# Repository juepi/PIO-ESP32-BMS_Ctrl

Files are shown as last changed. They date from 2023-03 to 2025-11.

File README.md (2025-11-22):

# Introduction 
This project is intended to be used as an WiFi/MQTT interface to the [Daly Smart BMS Systems](https://www.aliexpress.com/store/4165007) and Victron VE.Direct devices based on my PlatformIO ESP32 Template.  
Primarily, the code reads status data from the Daly BMS, Victron VE.Direct PV charger and SmartShunt and sends it to your MQTT broker at a configurable interval. It automatically switches the load-SSR on if the batteries are fully charged (2 configurable SOC limits) and off if the batteries are drained (also configureable SOC limit). Load-SSR can also be switched manually by setting the corresponding MQTT topic to `on` or `off`. The primary source for the battery SOC is the **Victron SmartShunt**.  
Last but not least, the firmware also allows you to handle an external active balancer through an additional SSR as recommended by [Andy](https://www.youtube.com/watch?v=yPmwrPOwC3g). However, i have added a second condition beside the 3.4V cell voltage: we're only enabling the active balancer if the voltage difference between the highest and lowest cell is above an configurable threshold (defaults to 30mV, configurable via MQTT topic `t_Ctrl_Cfg_SSR2_CdiffOn`).  
To configure the firmware for your needs, see files `user-config.h` and `mqtt-ota-config.h`, also see [**PlatformIO ESP32 Template**](https://github.com/juepi/PIO-ESP32-Template) readme (WiFi setup etc.).

## Mandatory Hardware Requirements
- 1x [WEMOS S2 Mini](https://www.wemos.cc/en/latest/s2/s2_mini.html) or any other ESP32 should work (adopt `platformio.ini`to your needs)
- 1x [Daly Smart BMS Systems](https://www.aliexpress.com/store/4165007) with UART port
- a Lithium battery fitting your requirements and BMS
- 1x [Victron SmartSolar](https://www.victronenergy.com/solar-charge-controllers/smartsolar-100-30-100-50) charger (or any other charger supporting the text version of the VE.Direct protocol)
- 1x [Victron SmartShunt](https://www.victronenergy.com/battery-monitors/smart-battery-shunt) with the amps required for your setup
- 3x [ADUM1201 UART Isolators](https://www.amazon.de/s?k=adum1201) or any other digital isolators you prefer
- 1x [AQW212EH Optocoupler](https://na.industrial.panasonic.com/products/relays-contactors/semiconductor-relays/lineup/photomos-relays/series/12512/model/12513)
- 1x [Active Balancer](https://aliexpress.com/item/4001176521939.html)
- a local WiFi network with a MQTT broker
- Sunlight. :wink:

## Status
What you are looking at here is the **second major release** of this firmware. If you want to see how it all started or you're interested in the problems I've encountered up to this point, take a look at the [final v1 release readme](https://github.com/juepi/PIO-ESP32-BMS_Ctrl/tree/v1.3.0).  
The hardware part is also finished now, see [KiCad folder](https://github.com/juepi/PIO-ESP32-BMS_Ctrl/tree/main/KiCad).

## Safety Guide
Keep in mind that you are working with potentially dangerous electricity levels depending on the hardware you use. Take any precautions necessary!

## Local Requirements
You need to do the initial battery setup on the Daly BMS using the included Bluetooth adapter and Daly's SmartBMS app, as the used [library](https://github.com/maland16/daly-bms-uart) does not support setting configuration parameters. Victron devices can use the VictronConnect App in parallel to the (read only) serial output on the VE.Direct port.  
An active balancer is highly recommended, as the internal passive balancer of the Daly BMS is useless. [Andy from the Off-Grid Garage](https://www.youtube.com/watch?v=yPmwrPOwC3g) has picked up this topic recently, and i've decided to add the active-balancing control as he suggests it into the firmware. Note that you will need an active balancer that will allow you to start the balancing by shorting 2 pins, like [this one from AliExpress](https://aliexpress.com/item/4001176521939.html). You will need to remove the solder chunk from the pads labeled "Run", this will reveal 2 seperate soldering pads. Solder 2 wires to the pads and connect them to an optocoupler output, in example [AQW212EH](https://na.industrial.panasonic.com/products/relays-contactors/semiconductor-relays/lineup/photomos-relays/series/12512/model/12513).

## An important notice on connecting the ESP32 to your BMS and VE.Direct
Take caution when connecting the ESP to the UART ports: the internal electronics of the BMS (including UART port) use "battery ground", whereas other connected devices (i.e. load, charger) use the "power ground". **NEVER EVER** connect these different grounds or magic smoke will leave your electronics! To avoid this, make sure to isolate **anything** coming from or going into the UART ports of the Daly BMS and your VE.Direct devices. For UART RX/TX, a **ADUM1201** isolator chip works well for me.

## Credits
Thanks to [maland16 and softwarecrash](https://github.com/maland16/daly-bms-uart) for providing a library to interact with the Daly Smart BMS.  
Thanks to [cterwilliger](https://github.com/cterwilliger/VeDirectFrameHandler/tree/master) for his Victron VE.Direct frame handler, which has been integrated into this project since v1.2.0. Note that the source is in the lib directory, not from github, as i needed to include [the buffer overflow patch](https://github.com/cterwilliger/VeDirectFrameHandler/pull/10). I have also added a frameCounter which increments when a valid frame is decoded (to ease handling of fresh data) and a function which looks up array index numbers by Name label (required for SmartShunt!).

# Bugs and Workarounds
- Both data frame arrays of the VeDirectFrameHandler (Charger and SmartShunt) keep increasing over time due to transmission/decoding errors (I assume!) leading to new (non-existing) data labels/values that are added to the arrays. VeDirectFrameHandler maxes out at 40 Labels, so this should not lead to any problems (in terms of buffer overflow), not sure how this is possible however as every frame has a checksum. Due to this problem, also garbage values will be decoded every now and then, so I've added additional validity checks when new data was received (especially SoC).
- VeDirectFrameHandler data from the SmartShunt is "sorted" randomly in the veValue/veName arrays, which breaks the "hardcoded" index numbers I used to get the values from the data arrays. I've fixed this by adding a function to the library that allows you to fetch the arrays index number from a given veName tag. This may also happen with data from the SmartSolar chargers (one out of 2 chargers show this "problem" in my setup).
- OneWire doesn't seem to work on high-numbered GPIO pins (tested with > 36); using IO4 works fine!
- It seems that a high frequency toggling of SSR1 and SSR3 relay may occured at firmware boot - i have not been able to identify the root cause, it only happens when the SSRs automatic-mode is enabled. Done some obviously not so successful improvements over time, but as of **v2.6.1** this error still seems to occur randomly. My latest idea on how to work around this issue was to delay handling of the "auto" SSR settings for 15sec after firmware boot with **v2.7.0**. Time will tell if this helped, first tests look promising.
- An **"offgrid mode"** has been added (**v2.4.3**) as i've experienced that certain battery loads (like my offgrid inverter) causes the OneWire communication to fail. I assume that the inverter causes high noise on the DC wires, but as only OneWire communication is affected, i decided to add this MQTT on/off switchable function to allow skipping OneWire readouts (all sensors will be set to 11°C in offgrid mode, see `t_Ctrl_Cfg_Offgrid_Mode` in `user-config.h`). Plugging in the offgrid inverter is only done in case of a long lasting power outage, which has not happened yet (and hopefully never will), so i can live with that limitation. **A note on failing OneWire communication:** in my case the only way to recover OW-communication was to power down the ESP (remove power from the OW sensors), it seems that the controller inside the sensors hung and rebooting the ESP did not help.
- Although all serial communication to the BMS and Victron devices uses some sort of CRC, it rarely happens that implausible values are reported. To avoid reacting with failsafe actions due to wrong values, several plausibility checks have been added starting with `v2.0.2`.

# Version History

## v2.0.0
- Initial Commit, removed overhead from v1
- Improved handling of SSRs (manual switching through MQTT)

## v2.0.1
- Added condition to enable balancer on large cell voltage diff
- Removed condition to enable balancer on PV power threshold
- removed balancer "minimum ON duration" timer
- cleaned up serial connection state handling
- added more textual output to `CtrlStatTXT` topic; now publishes info on every action the controller takes (like enable/disable load or balancer)

## v2.0.2
- MQTT topic `Daly_dV` now reports mV
- Sending int instead of float  to MQTT topics for Daly temperature and SOC
- Added error detection for VE.Direct data readouts (SOC)
- Added some currently unused pin defines to match KiCad schematics
- Added additional plausibility check for SoC data from SmartShunt

## v2.0.3
- Added optional OneWire support for DS18B20 temperature sensors (enable in `platformio.ini`) - doesn't work yet

## v2.0.4
- Moved OneWire GPIO to IO4, this one works

## v2.1.0
- Fixed missing VeDirectFrameHandler lib (**see Note below!**), which i've trashed somehow as it seems..; now loaded through `platformio.ini`
- Fixed Hostname limitation of ESP32-Template
- Renamed `user_setup.h` to more suitable `user-config.h`

## v2.1.1
- Added SSR3 and SSR4 initialization (default state OFF)
- Fixed high delays due to OneWire `getTempCByIndex()` calls when no sensors are available
- Added Timeout handling for OneWire sensors
- Improved VE.Direct data error and connection handling
- Bugfix for WiFi hostname setup (compile error for v2.1.0 when using hostname with dash)
- Added SSR3 for manual switching through MQTT
- Added safety shutdown of loads when communication to Daly BMS or Victron SmartShunt runs into timeout

## v2.2.0
- Reworked Load and Balancer SSR handling (now fully configurable through MQTT topics)
- Updated MQTT subscription handling (PIO-ESP32-Template v1.1.0)
- OTA Updates are now mandatory
- Removed MQTT control of Daly BMS FETs (they are a safety feature, you shouldn't mess with them manually)
- Added additional safety features (Balancer alarm mode for high cellDiff, load shutdown for minimum battery voltage)

## v2.2.1
- Re-added periodic publishing of SSR states (basically for plots in FHEM)
- Bugfix on SSR state handling at firmware boot

## v2.3.0
- Added ability to run without WiFi / MQTT broker connection (based on [**PIO-ESP32-Template v1.2.0**](https://github.com/juepi/PIO-ESP32-Template))

## v2.3.1
- Removed unneccesary SSR handling at firmware boot (just let auto-mode do the magic)
- Setting all SSR state topics to "OFF" on the broker at startup to match the actual firmware boot state 
- High frequency toggling of SSR3 state at firmware boot hopefully fixed

## v2.4.0
- Added error/recovery handling for over-temperature situations (OW-sensors and Daly BMS sensor)
- Improved under-voltage and communication error/recovery handling
- Removed Balancer Alarm mode, as balancing an empty battery does not make sense
- Added additional safety check to turn off loads at high cell diff voltage (stopping discharge should probably not further increase cell diff)
- Added verification of Daly celldiff readout (reports implausible high changes between 2 readouts in rare occurences)

## v2.4.1
- Minor status output changes (investigating readout error loop on SmartShunt)
- Added ESP reboot when reaching configurable threshold of subsequent SmartShunt read failures (defaults to 60 -> 1 minute)

## v2.4.2
- No longer send Controller status text messages retained
- Added global controller Alarm flag being published via MQTT; if a safety function triggers a critical condition, the flag switches to "on" (see topic `t_Ctrl_Alarm` in `user-config.h`)
- "Bugfix" in SmartShunt SOC verification ("error loop" from v2.4.1 - basically `VSS_MAX_SOC_DIFF` was set too low to 0.5% instead of 5%)

## v2.4.3
- Added status text message when not discarding unrealistic high Daly BMS voltage diff
- Increased max number of unrealistic subsequent voltage diff values from Daly BMS which will be discarded (from 2 to 4)
- Switched balancer power-off condition from single cell to all cells below `SSR2.CVOff` (previous conditions could lead to Auto-mode rapidly toggling balancer if a single cell is above enable and another one is below disable voltage)
- Added "offgrid mode", can be enabled when "noisy" battery loads break OneWire communication (in example, when connecting an offgrid inverter)

## v2.4.4
- Allow larger SOC changes when charger switches to absorption mode (battery full -> SmartShunt corrects SOC to 100%)

## v2.5.0
- Functionality cleanups
    - Removed Low-PPV threshold (everything below High-PPV threshold is considered as low now)
    - Removed Low/High-PPV Off-SOC for SSRs (simply useless - switched to a single Off-SOC)
- Removed ESP reboot for SmartShunt read failures (useless)

## v2.5.1
- Use Victron SmartShunt voltage (instead of Daly data) as battery pack voltage source for safety checks
- recover previous SSR Auto-mode settings instead of enabling all auto modes when recovering from critical states

## v2.6.0
- Added support for optional 2nd SmartSolar charger (VE.Direct, using GPIO39 for RX; enable in `platformio.ini`)
- Upgraded to latest `EspSoftwareSerial` library version
- Added plausibility check for SmartShunt pack voltage (discard value if difference to previous readout is more than `VSS_MAX_V_DIFF` defined in `user-config.h`)

## v2.6.1
- Immediately publish Controller-Alarm flag via MQTT when alarm occurs (or recovers)
- Fixed error in cell temperature alarm handling

## v2.7.0
- Added web interface (network status checking / reboot ESP)
- Upgraded underlying [**PIO-ESP32-Template to v1.4.0**](https://github.com/juepi/PIO-ESP32-Template)
- Checking validity of most important Victron SmartShunt data 10sec after firmare startup (ESP will reboot if no valid SOC or voltage is available)
- Automatic SSR-handling is started 15sec after ESP boot if enabled (hopefully solves fast-toggling SSR issue)
- Publishing of data to MQTT will start after `DATA_UPDATE_INTERVAL` to avoid publishing wrong/incomplete data directly at firmware boot

## v2.7.1
- Added Moving Average class to calculate short (1 min) and long (1hr) averages for Victron chargers PPV values
- Added validation of OneWire temperature readouts (reject reading if diff between subsequent readouts is higher than `OW_MAX_TEMP_DIFF`)
- Updated DallasTemperature library to [version 4.0.5](https://registry.platformio.org/libraries/milesburton/DallasTemperature)

# NOTE on missing VeDirectFrameHandler library

I somehow managed to not to include the VeDirectFrameHandler library into previous commits as it was intended. **This affects all versions prior v2.1.0!**  
If you want to build an older release, you can easily fix this by adding my [fork of VeDirectFrameHandler](https://github.com/juepi/VeDirectFrameHandler) into the library section of `platformio.ini`:

```
lib_deps =
    https://github.com/juepi/VeDirectFrameHandler
    ...
```

Have fun,  
Juergen

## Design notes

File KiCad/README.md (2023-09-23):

# KiCad Project Files
The hardware part of the BMS-Controller constists of 2 boards, where the small and simple DE-9 Adaptor board is meant to be placed in your battery box. It will only concentrate all required wires on a 9pin D-Sub connector, allowing you to use a common (straight) serial cable to connect to the actual BMS-Controller board with the ESP32 (which is located outside of the metal battery box in my case).  
Schematics should be straight forward and documented. Don't forget to add isolators into the wires to/from VE.Direct devices and your Daly BMS (i have soldered them directly into the wires, so they are not on the PCBs). Both PCBs only use THT parts (no SMT).

## Optional Features
I have added a second AQW212EH opto-coupler as well as 2 additional dual P-channel MOSFET driven power outputs. This hardware is optional. Depending on your load currents, you may install the paralleled MOSFETs (Q4-Q6) or not. I have done load tests with 2 paralleled MOSFETs with up to 15A without any problems. Do note that you will probably have to install more powerful MOSFETs with lower RDSon than the one mentioned in the schematics for such high currents. I have tested with 2 [IXYS IXTP140P05T](https://www.littelfuse.com/media?itemid=309f84bc-aa60-4d40-b2f9-2c59ecb0b7b8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). Additionally, you may want to screw at least small heat sinks to the FETs at this current levels.  
Additionally, i have prepared a pin header connector on the DE-9 adaptor board which will let you connect up to 5 [DS18B20](https://www.analog.com/media/en/technical-documentation/data-sheets/ds18b20.pdf) OneWire temperature sensors in parasitic mode.  
J4 and J5 can be used if you have an "external use" for the OptoMOS outputs of U2. Be sure not to place any other components on the OptoMOS output if you want to use the "external connector" (for J4 -> do not populate R2, R6 and R7, and of course Q2 and Q5) to keep them potential free.

## Production Files
Gerber files are prepared for PCB manufacturing at [jlcpcb.com](https://jlcpcb.com). If you are expecting higher currents on the power outputs, you may want to double up the **copper weight to 2oz** for the BMS-Controller PCB on your order.

# Version History

## v1.1
- Initial commit with some improvements to allow more current on BMS-Controller board (SSR1, SSR3 and SSR4)

## v1.2
- Replaced B2B-XH connector footprints with version w/o guidance hole
- maximized spacing between 2 paralleled MOSFETs to allow mounting a TO-220 heat sink
- Fixed too narrow GND connections for screw terminals; updated Gerber data
- Added silkscreen text to explain installation direction of ESP module

## v1.3
- Re-routed OneWire pin to GPIO4 (tested ok with 2 sensors)

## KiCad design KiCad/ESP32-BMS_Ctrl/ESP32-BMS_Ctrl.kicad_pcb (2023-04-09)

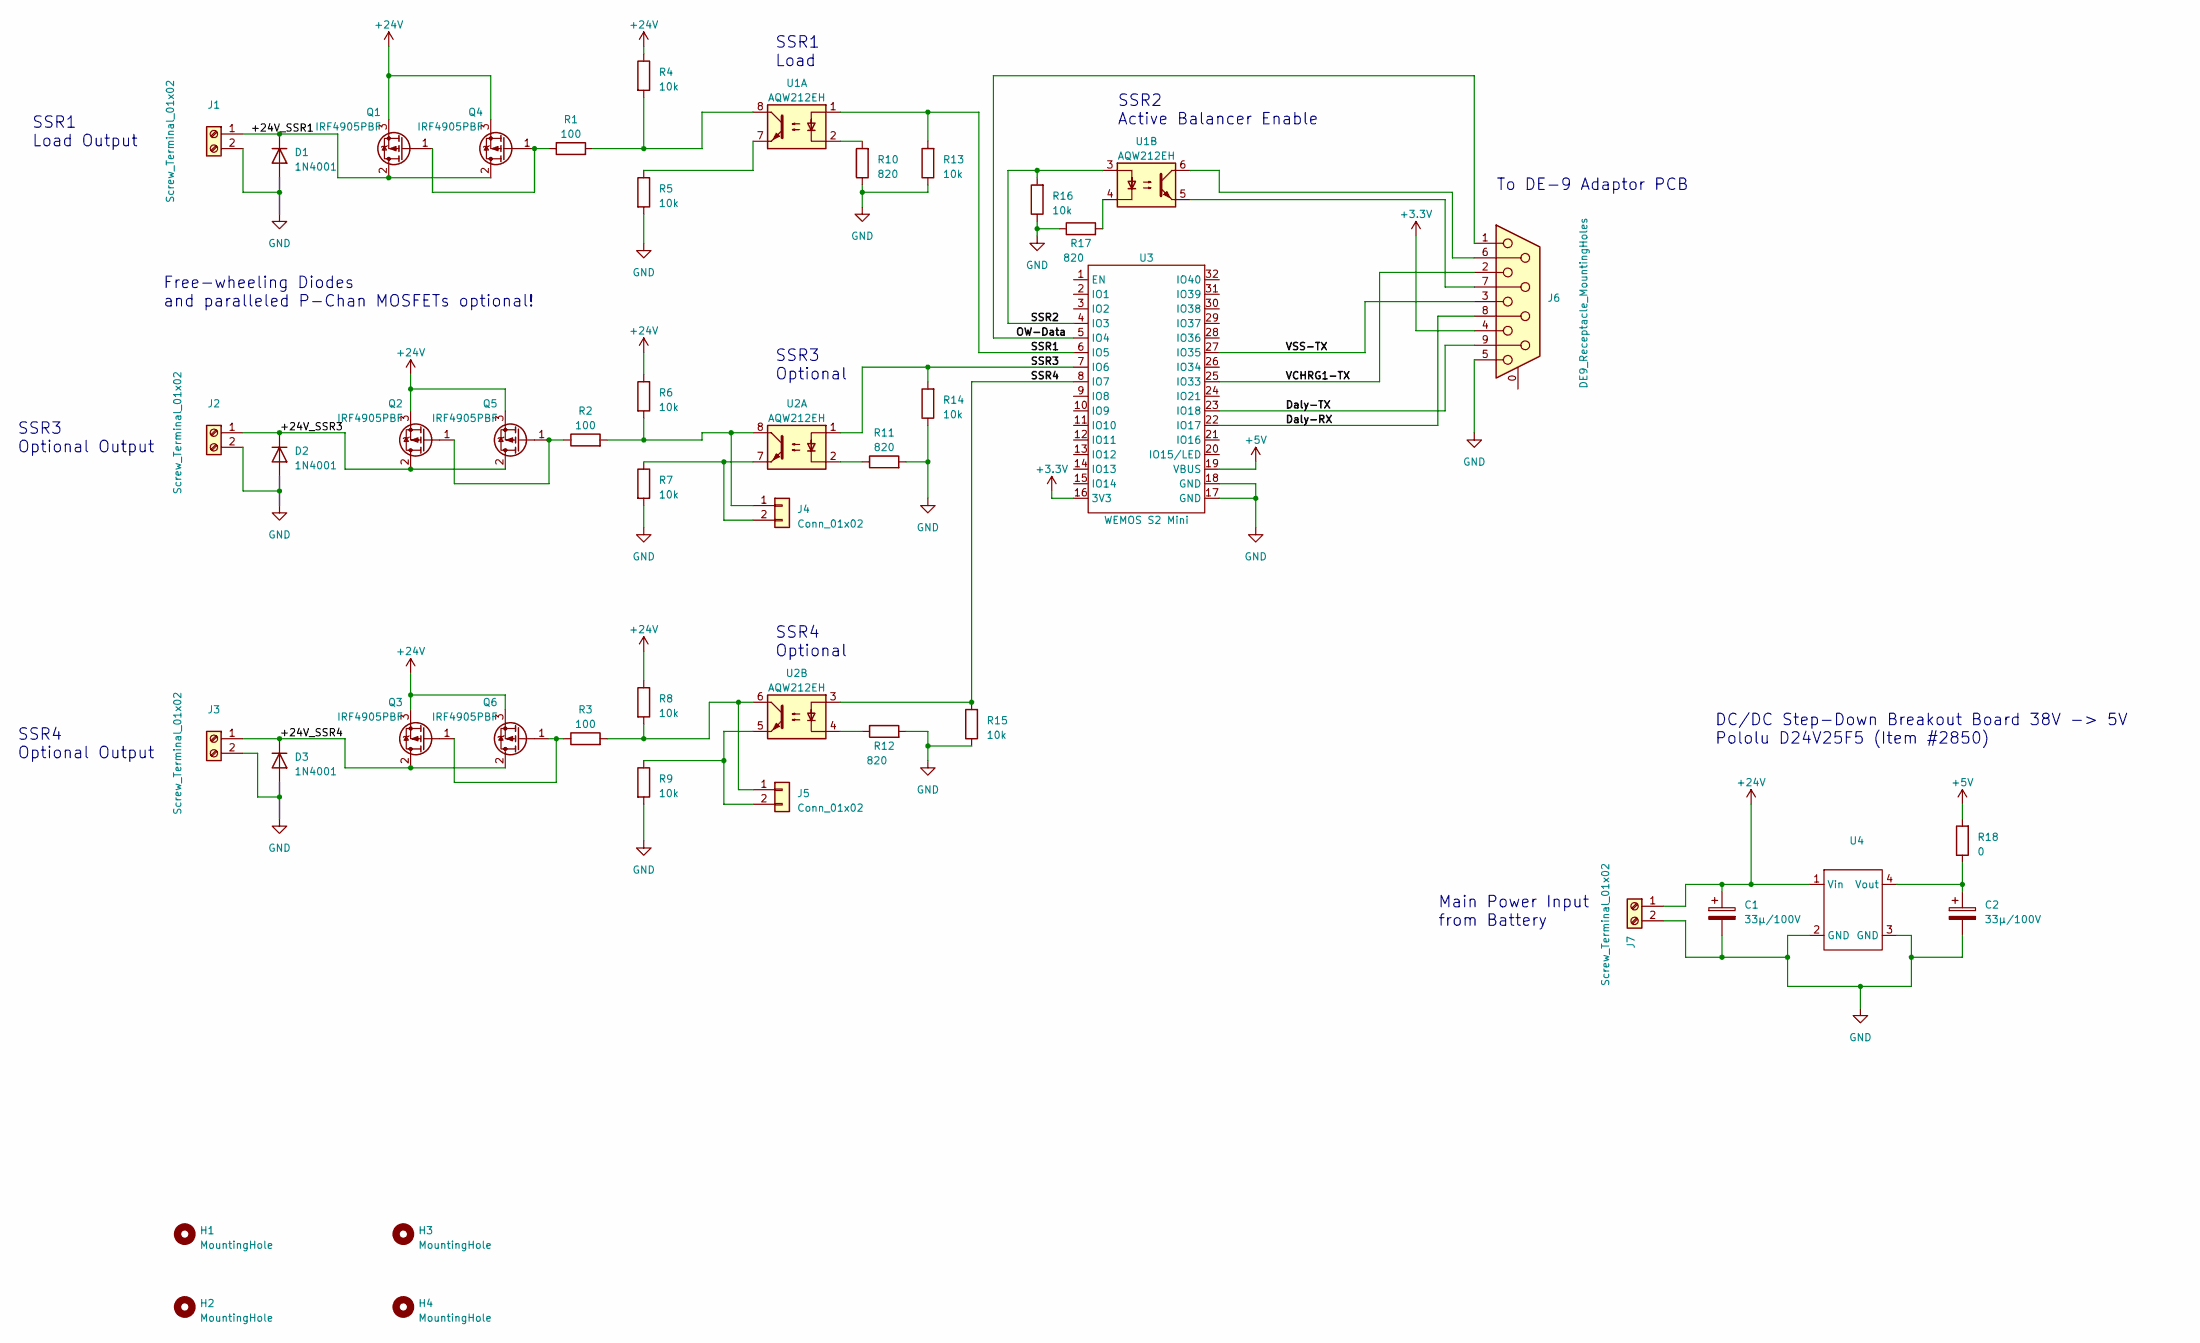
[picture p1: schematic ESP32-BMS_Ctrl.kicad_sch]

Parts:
C1, C2: 33µ/100V; CP_Radial_D10.0mm_P5.00mm
D1, D2, D3: 1N4001; D_DO-41_SOD81_P10.16mm_Horizontal
H1, H2, H3, H4: MountingHole; MountingHole_3.2mm_M3
J1, J2, J3, J7: Screw_Terminal_01x02; TerminalBlock_1x02_P5.00mm_Horizontal
J4, J5: Conn_01x02; JST_XH_B2B-XH-A_1x02_P2.50mm_Vertical
J6: DE9_Receptacle_MountingHoles; DSUB-9_Female_Horizontal_P2.77x2.84mm_EdgePinOffset9.90mm_H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
Q1, Q2, Q3, Q4, Q5, Q6: IRF4905PBF; TO-220-3_Vertical
R1, R2, R3: 100; R_Axial_DIN0207_L6.3mm_D2.5mm_P10.16mm_Horizontal
R4, R5, R6, R7, R8, R9, R13, R14, R15, R16: 10k; R_Axial_DIN0207_L6.3mm_D2.5mm_P10.16mm_Horizontal
R10, R11, R12, R17: 820; R_Axial_DIN0207_L6.3mm_D2.5mm_P10.16mm_Horizontal
R18: 0; R_Axial_DIN0207_L6.3mm_D2.5mm_P10.16mm_Horizontal
U1, U2: AQW212EH; DIP-8_W7.62mm_Socket
U3: WEMOS S2 Mini; WEMOS_S2_Mini
U4: Pololu_D24V25F5

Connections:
+3.3V: J6.4, U3.16 (3V3)
+5V: R18.2, U3.19 (VBUS)
+24V: C1.1, J7.1, Q1.3 (S), Q2.3 (S), Q3.3 (S), Q4.3 (S), Q5.3 (S), Q6.3 (S), R4.1, R6.1, R8.1, U4.1 (Vin)
/+24V_SSR1: D1.1 (K), J1.1, Q1.2 (D), Q4.2 (D)
/+24V_SSR3: D2.1 (K), J2.1, Q2.2 (D), Q5.2 (D)
/+24V_SSR4: D3.1 (K), J3.1, Q3.2 (D), Q6.2 (D)
/Daly-RX: J6.8, U3.22 (IO17)
/Daly-TX: J6.9, U3.23 (IO18)
/OW-Data: J6.1, U3.5 (IO4)
/SSR1: R13.2, U1.1, U3.6 (IO5)
/SSR2: R16.2, U1.3, U3.4 (IO3)
/SSR3: R14.2, U2.1, U3.7 (IO6)
/SSR4: R15.2, U2.3, U3.8 (IO7)
/VCHRG1-TX: J6.2, U3.25 (IO33)
/VSS-TX: J6.3, U3.27 (IO35)
GND: C1.2, C2.2, D1.2 (A), D2.2 (A), D3.2 (A), J1.2, J2.2, J3.2, J6.5, J7.2, R5.2, R7.2, R9.2, R10.1, R11.2, R12.2, R13.1, R14.1, R15.1, R16.1, R17.1, U3.17 (GND), U3.18 (GND), U4.2 (GND), U4.3 (GND)
unnamed: J4.1, R2.2, R6.2, U2.8
unnamed: J4.2, R7.1, U2.7
unnamed: J5.1, R3.2, R8.2, U2.6
unnamed: J5.2, R9.1, U2.5
unnamed: J6.6, U1.6
unnamed: J6.7, U1.5
unnamed: Q1.1 (G), Q4.1 (G), R1.1
unnamed: Q2.1 (G), Q5.1 (G), R2.1
unnamed: Q3.1 (G), Q6.1 (G), R3.1
unnamed: R1.2, R4.2, U1.8
unnamed: R5.1, U1.7
unnamed: R10.2, U1.2
unnamed: R11.1, U2.2
unnamed: R12.1, U2.4
unnamed: R17.2, U1.4
unnamed: C2.1, R18.1, U4.4 (Vout)

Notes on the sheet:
To DE-9 Adaptor PCB
Main Power Input from Battery
SSR4 Optional Output
Free-wheeling Diodes and paralleled P-Chan MOSFETs optional!
SSR2 Active Balancer Enable
SSR4 Optional
SSR3 Optional
DC/DC Step-Down Breakout Board 38V -> 5V Pololu D24V25F5 (Item #2850)
SSR1 Load
SSR1 Load Output
SSR3 Optional Output

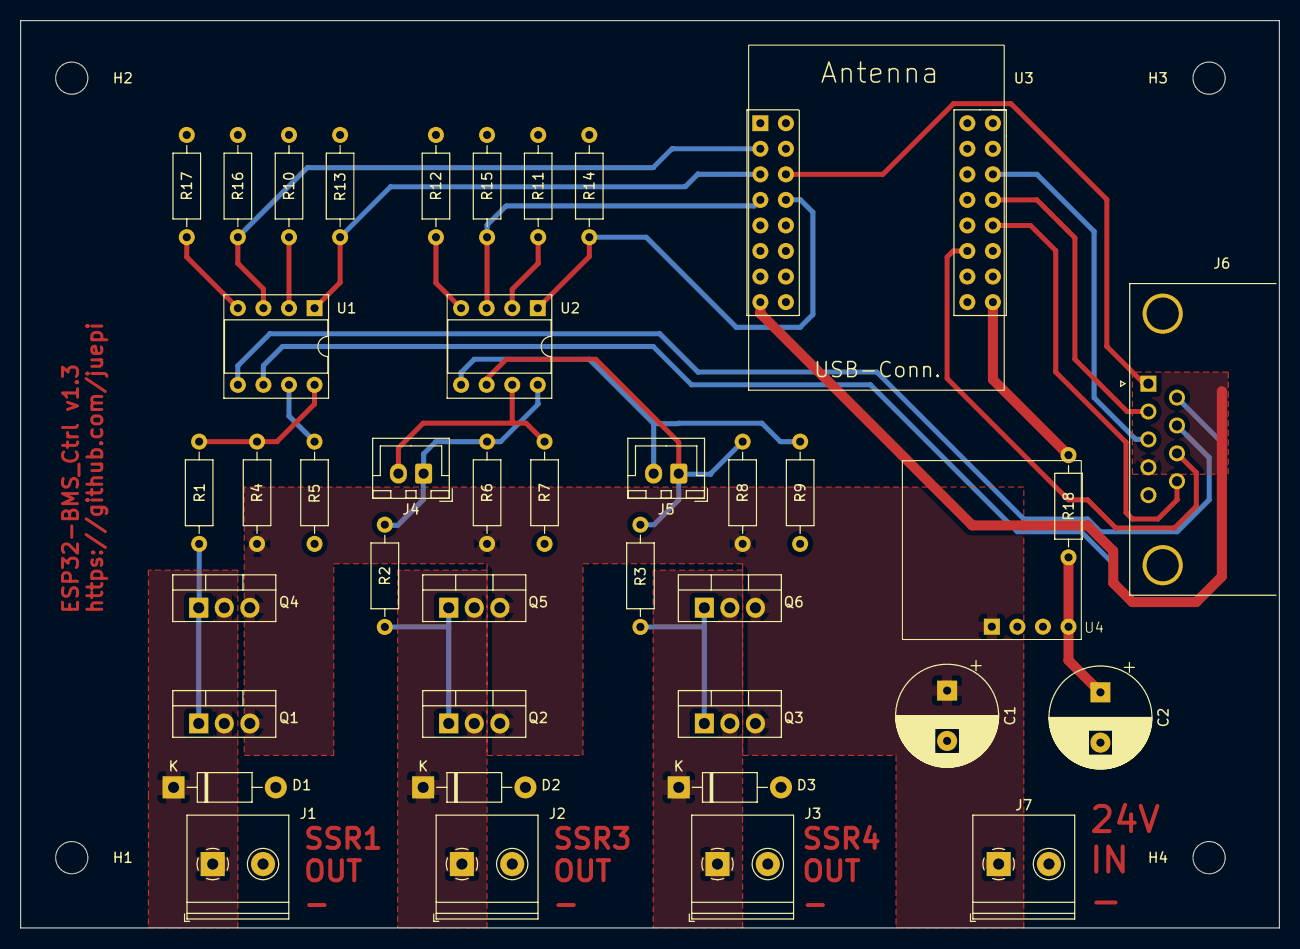
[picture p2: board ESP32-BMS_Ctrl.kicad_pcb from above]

Board: 2 copper layers, 125.1 x 90.2 mm, 44 parts (0 on the bottom side), 32 nets.

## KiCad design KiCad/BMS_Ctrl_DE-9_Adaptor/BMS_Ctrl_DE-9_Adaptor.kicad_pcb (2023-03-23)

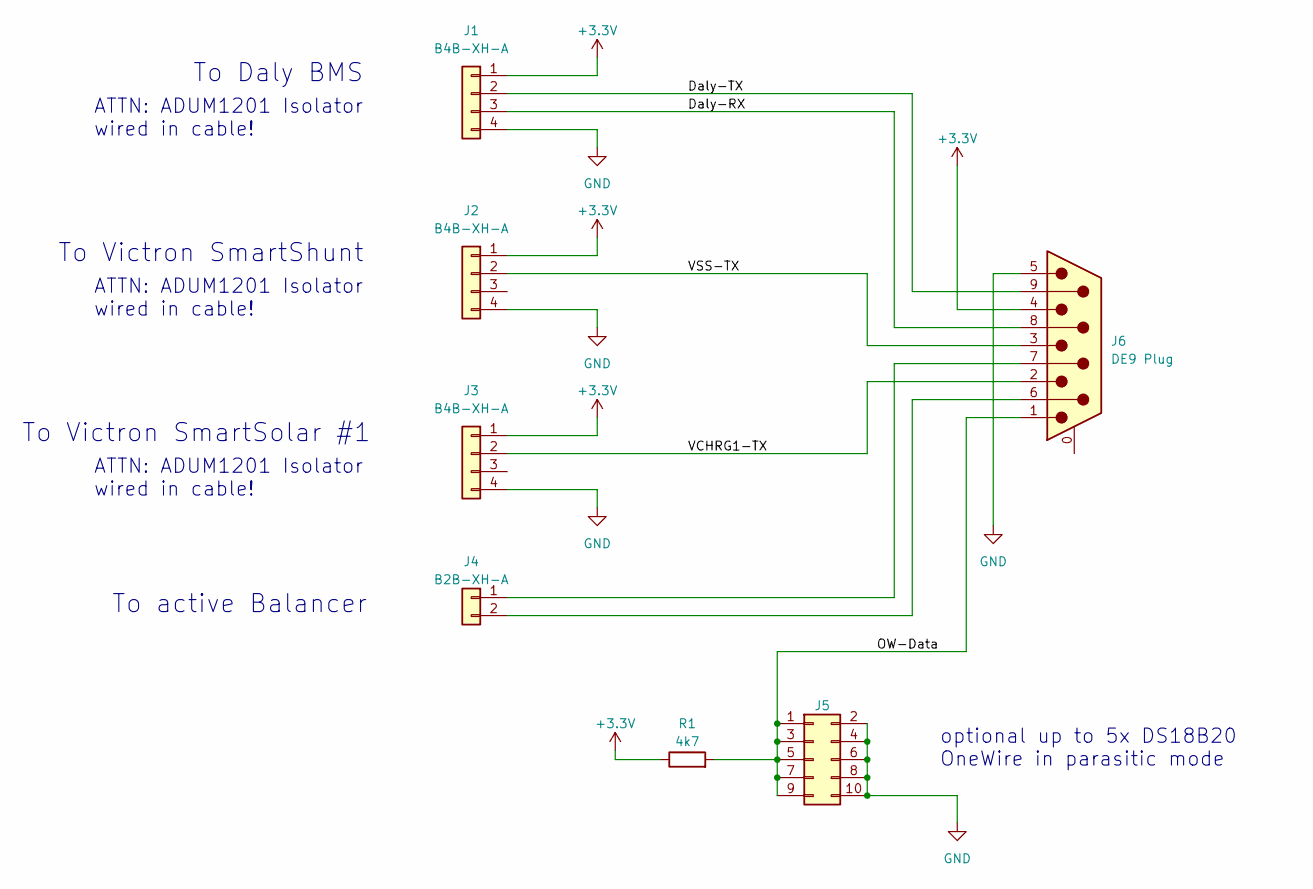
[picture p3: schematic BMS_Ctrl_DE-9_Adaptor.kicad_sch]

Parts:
J1, J2, J3: B4B-XH-A; JST_XH_B4B-XH-A_1x04_P2.50mm_Vertical; Manufacturer_Part_Number B4B-XH-A(LF)(SN)
J4: B2B-XH-A; JST_XH_B2B-XH-A_1x02_P2.50mm_Vertical; Manufacturer_PN B2B-XH-A(LF)(SN)
J5: Conn_02x05_Counter_Clockwise; PinHeader_2x05_P2.54mm_Vertical
J6: DE9 Plug; DSUB-9_Male_Horizontal_P2.77x2.84mm_EdgePinOffset9.90mm_Hou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
R1: 4k7; R_Axial_DIN0207_L6.3mm_D2.5mm_P10.16mm_Horizontal

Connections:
+3.3V: J1.1, J2.1, J3.1, J6.4, R1.1
/Daly-RX: J1.3, J6.8
/Daly-TX: J1.2, J6.9
/OW-Data: J5.1, J5.3, J5.5, J5.7, J5.9, J6.1, R1.2
/VCHRG1-TX: J3.2, J6.2
/VSS-TX: J2.2, J6.3
GND: J1.4, J2.4, J3.4, J5.2, J5.4, J5.6, J5.8, J5.10, J6.5
unnamed: J4.1, J6.7
unnamed: J4.2, J6.6

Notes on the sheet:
To Victron SmartSolar #1
ATTN: ADUM1201 Isolator wired in cable!
To Daly BMS
To active Balancer
To Victron SmartShunt
optional up to 5x DS18B20 OneWire in parasitic mode

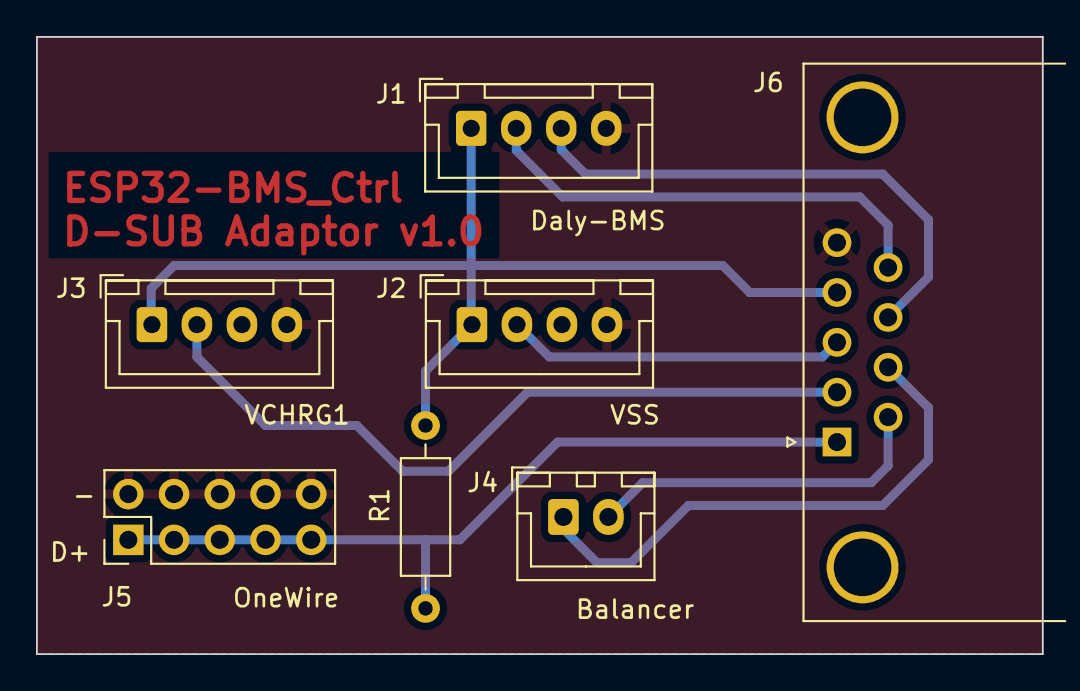
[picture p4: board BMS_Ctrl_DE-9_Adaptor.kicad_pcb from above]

Board: 2 copper layers, 55.9 x 34.3 mm, 7 parts (0 on the bottom side), 9 nets.

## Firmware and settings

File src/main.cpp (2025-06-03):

/*
 * ESP32 Template
 * ==================
 *
 * Includes useful functions like
 * - DeepSleep
 * - MQTT
 * - OTA Updates (ATTN: requires MQTT!)
 *
 */
#include <setup.h>

/*
 * Main Loop
 * ========================================================================
 */
void loop()
{
#ifdef WIFI_DELAY
  static unsigned long start_user_loop = 0;
  static unsigned long duration_user_loop = 0;
#endif
  static unsigned long netfail_reconn_millis = 0;
  static unsigned int netfail_reconn_tries = 0;
  // Uptime calculation
  static unsigned long oldMillis = 0;

  // Handle Uptime counter
  if ((millis() - oldMillis) >= 1000)
  {
    oldMillis = millis();
    UptimeSeconds++;
#ifdef ONBOARD_LED
    // Toggle LED every second
    ToggleLed(LED, 1, 1);
#endif
  }

//
// Handle local tasks
//
#ifdef READVCC
  // Read VCC every 10 seconds
  // AD conversion draws quite some power, so don't run too often
  static unsigned long Next_VCC_ADC = 0;
  if (millis() > Next_VCC_ADC)
  {
    VCC = VDIV * VFULL_SCALE * float(analogRead(VBAT_ADC_PIN)) / ADC_MAXVAL;
    Next_VCC_ADC = millis() + 10000;
  }
#endif

  //
  // Handle network / MQTT broker connection failures (NET_OUTAGE=1)
  //
  if (NetState == NET_FAIL)
  {
    // Currently no network available, try to recover
    if (millis() >= netfail_reconn_millis)
    {
      if (!WiFi.isConnected())
      {
        // WiFi down, try to restart WiFi
        wifi_down();
        delay(100);
        wifi_up();
        delay(100);
      }
      // and try to reconnect to Broker
      if (WiFi.isConnected())
      {
        MqttUpdater();
      }
      if (NetState == NET_FAIL)
      {
        // Still no network/broker available, wait for NET_RECONNECT_INTERVAL
        netfail_reconn_millis = millis() + NET_RECONNECT_INTERVAL;
        netfail_reconn_tries++;
#ifdef MAX_NETFAIL_RECONN
        if (netfail_reconn_tries > MAX_NETFAIL_RECONN)
        {
          // we've tried long enough, let's reset the ESP!
          ESP.restart();
        }
#endif // MAX_NETFAIL_RECONN
      }
      else
      {
        // Recovered from network outage
        NetRecoveryMillis = millis();
        netfail_reconn_millis = 0;
        netfail_reconn_tries = 0;
      }
    }
  }

  //
  // Handle network tasks
  //
  if (NetState == NET_UP)
  {
    // Check connection to MQTT broker, subscribe and update topics
    MqttUpdater();

    // Handle OTA updates
    if (OTAUpdateHandler())
    {
      // OTA Update in progress, restart main loop
      return;
    }
#ifdef READVCC
    // Publish VCC to MQTT
    static unsigned long Next_Mqtt_Publish = 0;
    if (millis() >= Next_Mqtt_Publish)
    {
      mqttClt.publish(vcc_topic, String(VCC).c_str(), true);
      delay(150);
      Next_Mqtt_Publish = millis() + (MQTT_PUB_INTERVAL * 1000);
      DEBUG_PRINTLN("VCC = " + String(VCC) + " V");
    }
#endif
  }
#ifdef NTP_CLT
  // Always update time variables, also when WiFi is off
  time(&EpochTime);
  getLocalTime(&TimeInfo, 200);
  if (TimeInfo.tm_year > 2023)
  {
    // System time is in the past, somethings wrong - retry
    getLocalTime(&TimeInfo, 200);
    if (TimeInfo.tm_year > 2023)
    {
      DEBUG_PRINTLN("Wrong system time, invalidating local time and retry in next loop");
      NTPSyncCounter = 0;
    }
  }
  // Prints formatted date and time
  // DEBUG_PRINTLN(&TimeInfo, "%A, %B %d %Y %H:%M:%S");
#endif
#ifdef MEASURE_SLEEP_CLOCK_SKEW
  static bool SkewDataSent = false;
  if (esp_reset_reason() == ESP_RST_DEEPSLEEP)
  {
    // Woke up from deepsleep, output some helpers to allow calculation of SLEEPT_CORR_FACT
    if (NTPSyncCounter > 0 && !SkewDataSent)
    {
      mqttClt.publish(boot_dur_topic, String(millis()).c_str(), false);
      mqttClt.publish(end_sleep_topic, String(EpochTime).c_str(), false);
      SkewDataSent = true;
    }
  }
#endif

//
// Handle user_loop
//
#ifdef WIFI_DELAY
  // Run user specific loop and measure duration
  start_user_loop = millis();
  user_loop();
  duration_user_loop = millis() - start_user_loop;

  // Spare some CPU time for background tasks (if we're not in a hurry)
  if (duration_user_loop < 100)
  {
    delay(WIFI_DELAY);
  }
#else
  user_loop();
  yield();
#endif

//
// Handle SleepUntil
//
#ifdef SLEEP_UNTIL
  if (NTPSyncCounter > 0 && EpochTime < SleepUntilEpoch && !DelayDeepSleep)
  {
    time(&EpochTime);
    // System time synced and received sleep-until time in the future -> OK!
    // calculate time to sleep in µs
    uint64_t WakeAfter_us = (((uint64_t)SleepUntilEpoch - (uint64_t)EpochTime) * 1000000ULL);
#ifdef MEASURE_SLEEP_CLOCK_SKEW
    DEBUG_PRINTLN("Configured Sleep time in seconds: " + String(SleepUntilEpoch - EpochTime));
    DEBUG_PRINTLN("Epoch at start sleep: " + String(EpochTime));
    mqttClt.publish(set_sleep_dur_topic, String(SleepUntilEpoch - EpochTime).c_str(), false);
    mqttClt.publish(start_sleep_topic, String(EpochTime).c_str(), false);
    delay(100);
#endif
    wifi_down();
    esp_deep_sleep(WakeAfter_us);
  }
#endif

//
// Handle DeepSleep
//
#ifdef E32_DEEP_SLEEP
  if (!DelayDeepSleep)
  {
    // disconnect WiFi and go to sleep
    DEBUG_PRINTLN("Good night for " + String(DS_DURATION_MIN) + " minutes.");
    wifi_down();
    esp_deep_sleep((uint64_t)DS_DURATION_MIN * 60000000ULL);
  }
#endif

  // First iteration of main loop finished
  JustBooted = false;
}

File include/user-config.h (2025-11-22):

/*
 *   ESP32 Template
 *   User specific defines and Function declarations
 */
#ifndef USER_CONFIG_H
#define USER_CONFIG_H

#include "mqtt-ota-config.h"

//
// Define required user libraries here
// Don't forget to add them into platformio.ini or the /lib directory
//
#include <daly-bms-uart.h>
#include <VeDirectFrameHandler.h>
#include <SoftwareSerial.h>
#ifdef ENA_ONEWIRE // Optional OneWire support
#include <OneWire.h>
#include <DallasTemperature.h>
#endif
#include <AsyncTCP.h>
#include <ESPAsyncWebServer.h>

//
// Declare user_setup, user_loop and custom global functions
//
extern void user_setup();
extern void user_loop();
// Webserver functions
extern String processor(const String &var);
extern void notFound(AsyncWebServerRequest *request);

//
// Declare global user specific objects
//
extern Daly_BMS_UART bms;
extern SoftwareSerial VEDSer_Chrg1;
extern VeDirectFrameHandler VED_Chrg1;
#ifdef ENA_SS2
extern SoftwareSerial VEDSer_Chrg2;
extern VeDirectFrameHandler VED_Chrg2;
#endif
extern SoftwareSerial VEDSer_Shnt;
extern VeDirectFrameHandler VED_Shnt;
#ifdef ENA_ONEWIRE // Optional OneWire support
extern OneWire oneWire;
extern DallasTemperature OWtemp;
#endif

//
// Hardware Setup - User SSR
// HIGH level -> SSR is switched ON
//
#define PIN_SSR1 5 // Battery Load Switch 1
#define PIN_SSR2 3 // Active Balancer Enable
#define PIN_SSR3 6 // Battery Load Switch 2
#define PIN_SSR4 7 // unused - defined to match KiCad board

//
// Controller specific
//
// MQTT Topic Tree prepended to all topics
// ATTN: Must end with "/"!
#define TOPTREE "HB7/UG/BMS/"

// MQTT Topics for published data
#define t_Ctrl_StatT TOPTREE "CtrlStatTXT" // ESP Controller status text provided through MQTT
#define t_Ctrl_StatU TOPTREE "CtrlStatUpt" // ESP Controller uptime provided through MQTT
#define t_Ctrl_Alarm TOPTREE "CtrlAlarm"   // Global alarm flag to signal fail states (any Safety *Critical flag = TRUE)

//
// MQTT Data update interval
//
#define DATA_UPDATE_INTERVAL 120 // Send MQTT data ever x seconds

//
// SAFETY Features Thresholds
//
#define RECOVER_CELL_T 27.0f    // Recovery temperature threshold for cell temperatures
#define CRIT_CELL_T 35.0f       // Critical temperature threshold for cell temperatures
#define RECOVER_CHRG_T 32.0f    // Recovery temperature threshold for charger temperature
#define CRIT_CHRG_T 40.0f       // Critical temperature threshold for charger temperature
#define RECOVER_CELLDIFF 20.0f  // Recovery cell voltage difference (mV between highest and lowest cell)
#define CRIT_CELLDIFF 100.0f    // Critical cell voltage difference
#define RECOVER_BAT_LOW_V 25.4f // Recovery battery pack low voltage
#define CRIT_BAT_LOW_V 24.4f    // Critical battery pack undervoltage

// MQTT Topics (Subscriptions)
#define t_Ctrl_Cfg_Safety_CritCdiff TOPTREE "Cfg/Safety_CritCdiff" // MQTT configurable critical cell voltage difference in mV at which loads are disabled
#define t_Ctrl_Cfg_Offgrid_Mode TOPTREE "Cfg/Safety_OffgridMode"   // MQTT configurable offgrid mode [on/off] (disables OneWire sensors)

//
// OneWire Bus
//
#ifdef ENA_ONEWIRE             // Optional OneWire support
#define PIN_OWDATA 4           // GPIO for OneWire communication (Note: high GPIOs >36 do not work!)
#define OWRES 9                // Use 9 bits resolution (0.5°C)
#define NUM_OWTEMP 3           // Amount of connected DS18B20 sensors
#define OW_UPDATE_INTERVAL 5   // sensor readout interval in seconds
#define OW_TIMEOUT 60          // If no data update for all sensors occur within this timespan (seconds), connection to OneWire considered dead
#define i_C1_SENS 2            // DS18B20 sensor index for Cell 1 temperature (Hint: use a OneWire-temperature demo sketch to determine index values of your sensors!)
#define i_C8_SENS 0            // DS18B20 sensor index for Cell 8 temperature
#define i_CHRG_SENS 1          // DS18B20 sensor index for SmartSolar Charger
#define OW_MAX_TEMP_DIFF 30.0f // Max allowed temperature difference between subsequent readouts of a sensor (to detect faulty readings)

// MQTT Topics for published data
#define t_OW_TEMP_Templ TOPTREE "OW_T" // will be extended with sensor numbers starting at 1
#define t_OW_CSTAT TOPTREE "OW_CSTAT"
#endif // ENA_ONEWIRE

//
// Daly BMS Settings
//
// UART
// (defaults to GPIO17 for TXD and GPIO18 for RXD on ESP32-S2)
#define DALY_UART Serial1
// Data readout interval in seconds
#define DALY_UPDATE_INTERVAL 5
#define DALY_TIMEOUT 60 // If no data update occurs within this timespan (seconds), connection to Daly BMS considered dead

// Max difference between 2 readouts of cell voltage diff
#define MAX_CDIFF_DIFF 50.0f // readout with a higher difference to the previous readout will be discarded
#define MAX_IGNORED_CDIFF 4  // if 4 subsequent readouts are "unrealistic", we have to assume that they aren't..
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

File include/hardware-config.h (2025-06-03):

/*
 *   ESP32 Template
 *   Hardware / Board specific Settings
 */
#ifndef HARDWARE_CONFIG_H
#define HARDWARE_CONFIG_H

//
// WEMOS Lolin32 Board
//
#ifdef WEMOS_LOLIN32
// Onboard LED
#define LED 5
// LED is active low
#define LEDON LOW
#define LEDOFF HIGH

// Pin used for reading VCC (ADC1 channel 7, Pin 35)
// ==================================================
// LOLIN32 uses 100k/27k voltage divider (factor 4.7) on board
// DOCS: https://docs.espressif.com/projects/esp-idf/en/latest/esp32/api-reference/peripherals/adc.html
// and: https://randomnerdtutorials.com/esp32-adc-analog-read-arduino-ide/
// BOARD: https://metalab.at/wiki/Wemos_LOLIN32
#define VBAT_ADC_PIN 35
#define VDIV 4.7f
#define ADC_ATTENUATION ADC_0db
#define VFULL_SCALE 1.1f
#define ADC_CHAN ADC1_CHANNEL_7
#define ADC_RESOLUTION 12
#define ADC_MAXVAL 4095
// if READ_THROUGH_GPIO is defined, VCC will be read through the configured GPIO (must be connected to VBAT_ADC_PIN of course). The GPIO will be configured as output and set HIGH in the hardware_setup routine
// can have an advantage when running on batteries, as the external attenuator only draws current when the ESP is active
#define READ_THROUGH_GPIO 5

#endif // WEMOS_LOLIN32

//
// WEMOS S2 Mini (ESP32S2) Board
//
#ifdef WEMOS_S2MINI
// Onboard LED
#define LED 15
// LED is active high
#define LEDON HIGH
#define LEDOFF LOW

// Pin used for reading VCC (ADC1 channel 2, GPIO3)
// ==================================================
// Documentation: https://docs.espressif.com/projects/arduino-esp32/en/latest/api/adc.html#about
//
#define VBAT_ADC_PIN 3
#define VDIV 4.348f               // external attenuator on ESP-Mini-Base (https://github.com/juepi/ESP-Mini-Base); use 1 if no external attenuator is used
#define ADC_ATTENUATION ADC_2_5db // measureable voltage @2.5dB: 0..1050mV; adopt to your needs
#define VFULL_SCALE 1.1312f       // adopt to your hardware to increase accuracy
#define ADC_RESOLUTION 12         // bits
#define ADC_MAXVAL 4095
// if READ_THROUGH_GPIO is defined, VCC will be read through the configured GPIO (must be connected to VBAT_ADC_PIN of course). The GPIO will be configured as output and set HIGH in the hardware_setup routine
// can have an advantage when running on batteries, as the external attenuator only draws current when the ESP is active
#define READ_THROUGH_GPIO 5

#endif // WEMOS_S2MINI

//
// Additional Helpers for ESP-Mini-Base
// see: https://github.com/juepi/ESP-Mini-Base
//
#ifdef ESP_Mini_Base
#define EMB_FET_Q1 1      // Default IO gate Q1 FET
#define EMB_FET_Q2 2      // Default IO gate Q2 FET
#define EMB_ADC 3         // ADC1_2 with external attenuator
#define EMB_FET_Q3 4      // Default IO gate Q3 FET
#define EMB_VCC_MEASURE 5 // Suggested IO for measuring VCC (needs manual wiring to EMB_ADC)
#define EMB_SSR_U1 13     // Default IO for switching SSR U1 (high --> SSR short)
#define EMB_PWS_U2 14     // Default IO for switching supply-switch U2 (high -> output enabled)
#define EMB_SW1 16        // Default IO for Button SW1 (external pullup -> active low!)
#define EMB_LS_U4_1 11    // Levelshifter U4 port 1
#define EMB_LS_U4_2 8     // Levelshifter U4 port 2 (I2C SDA)
#define EMB_LS_U4_3 9     // Levelshifter U4 port 3 (I2C SCL)
#define EMB_LS_U4_4 7     // Levelshifter U4 port 4
#define EMB_LS_U5_1 37    // Levelshifter U5 port 1 (SPI MISO)
#define EMB_LS_U5_2 36    // Levelshifter U5 port 2 (SPI SCK)
#define EMB_LS_U5_3 35    // Levelshifter U5 port 3 (SPI MOSI)
#define EMB_LS_U5_4 33    // Levelshifter U5 port 4
#endif                    // ESP_Mini_Base

//
// ESP32-C6 based boards (Tested with AliExpress SuperMini boards)
//
#ifdef ESP32C6
// Onboard LED
#define LED 15
// Onboard WS2812 based RGB-LED
#define RGBLED 8
// LED is active high
#define LEDON HIGH
#define LEDOFF LOW
// Pin used for reading VCC (GPIO2)
// ==================================================
// Documentation: https://docs.espressif.com/projects/arduino-esp32/en/latest/api/adc.html#about
//
#define VBAT_ADC_PIN A2
#define VDIV 4.348f               // external attenuator on ESP-Mini-Base (https://github.com/juepi/ESP-Mini-Base); use 1 if no external attenuator is used
#define ADC_ATTENUATION ADC_2_5db // measureable voltage @2.5dB: 0..1050mV; adopt to your needs
#define VFULL_SCALE 1.1312f       // adopt to your hardware to increase accuracy
#define ADC_RESOLUTION 12         // bits
#define ADC_MAXVAL 4095
// if READ_THROUGH_GPIO is defined, VCC will be read through the configured GPIO (must be connected to VBAT_ADC_PIN of course). The GPIO will be configured as output and set HIGH in the hardware_setup routine
// can have an advantage when running on batteries, as the external attenuator only draws current when the ESP is active
#define READ_THROUGH_GPIO 5
#endif // ESP32C6

#endif // HARDWARE_CONFIG_H

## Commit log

2022-09-11 blindly added Daly BMS library
2023-01-01 reset platformio.ini to wired flash
2023-03-23 Added KiCad files; Firmware version 2.0.2
    [BMS_Ctrl_DE-9_Adaptor-B_Cu.gbl, BMS_Ctrl_DE-9_Adaptor-B_Mask.gbs, BMS_Ctrl_DE-9_Adaptor-B_Paste.gbp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]
2023-03-31 Updated Main PCB to v1.2
    [ESP32-BMS_Ctrl-B_Cu.gbl, ESP32-BMS_Ctrl-B_Mask.gbs, ESP32-BMS_Ctrl-B_Paste.gbp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]
2023-04-04 minor updates on main PCB
    [ESP32-BMS_Ctrl-B_Cu.gbl, ESP32-BMS_Ctrl-B_Mask.gbs, ESP32-BMS_Ctrl-B_Paste.gbp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]
2023-04-09 OneWire working now; updated KiCad data
    [ESP32-BMS_Ctrl-B_Cu.gbl, ESP32-BMS_Ctrl-B_Mask.gbs, ESP32-BMS_Ctrl-B_Paste.gbp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]
2023-04-14 v2.10; fixed missing VeDirectFH lib
    [setup.cpp, user-config.h]
2023-06-08 v2.3.1 - mainly bugfix release
    [user-config.h, user_setup_loop.cpp]
2023-06-26 minor improvements and fixes - v2.4.2
    [user-config.h, user_setup_loop.cpp]
2023-07-30 v2.4.3 - minor updates and workarounds
    [user-config.h, user_setup_loop.cpp]
2025-06-03 bugfixes and config updates
    [main.cpp, user-config.h, user_setup_loop.cpp]
2025-06-10 bugfix SS2 H20 Index detection
    [user_setup_loop.cpp]
